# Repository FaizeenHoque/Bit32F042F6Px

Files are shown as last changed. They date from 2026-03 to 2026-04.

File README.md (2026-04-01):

# Bit32F042F6Px

Minimal STM32F042F6Px development board. USB-C, GPIO headers, onboard 3.3V regulation. No peripherals, no bloat.

Licensed under [CERN-OHL-S v2](LICENSE).

---

## Features

- STM32F042F6Px (32KB Flash, 6KB RAM, 48MHz)
- USB-C (USB 2.0 Full Speed via PA11/PA12)
- LP5912-3.3DRV LDO — 3.3V regulated output from 5V USB
- BOOT0 and RESET buttons
- SWD header (SWDIO, SWCLK, 3.3V, GND)
- GPIO headers — all available pins broken out
- Power indicator LED

---

## Bill of Materials

| Designator | Footprint | Qty | Value |
|---|---|:---:|---|
| BOOT1, RESET1 | SW_SPST_B3U-1000P | 2 | SW_Push |
| C1 | 0402 | 1 | 0.1µF |
| C2, C4, C5 | 0402 | 3 | 1µF |
| C3 | 0402 | 1 | 10µF |
| D1 | 0402 | 1 | LED |
| J1 | USB_C_Receptacle_GCT_USB4105-xx-A_16P_TopMnt_Horizontal | 1 | USB_C_Receptacle_USB2.0_16P |
| J2, J3 | PinHeader_1x09_P2.54mm_Vertical | 2 | Conn_01x09 |
| J4 | PinHeader_1x04_P2.54mm_Vertical | 1 | Conn_01x04 |
| R1, R2 | 0402 | 2 | 10kΩ |
| R3, R4 | 0402 | 2 | 5.1kΩ |
| R5 | 0402 | 1 | 1kΩ |
| U1 | TSSOP-20_4.4x6.5mm_P0.65mm | 1 | STM32F042F6Px |
| U2 | WSON-6-1EP_2x2mm_P0.65mm_EP1x1.6mm_ThermalVias | 1 | LP5912-3.3DRV |

---

## Pinout

| Header | Pins |
|---|---|
| J2 | +5V, +3V3 (x2), GND, GPIO\_6, GPIO\_7, GPIO\_8, GPIO\_9, GPIO\_10 |
| J3 | +5V, GND, GPIO\_0–GPIO\_5, GND |
| J4 | +3V3, SWDIO, SWCLK, GND |

---

## Schematic

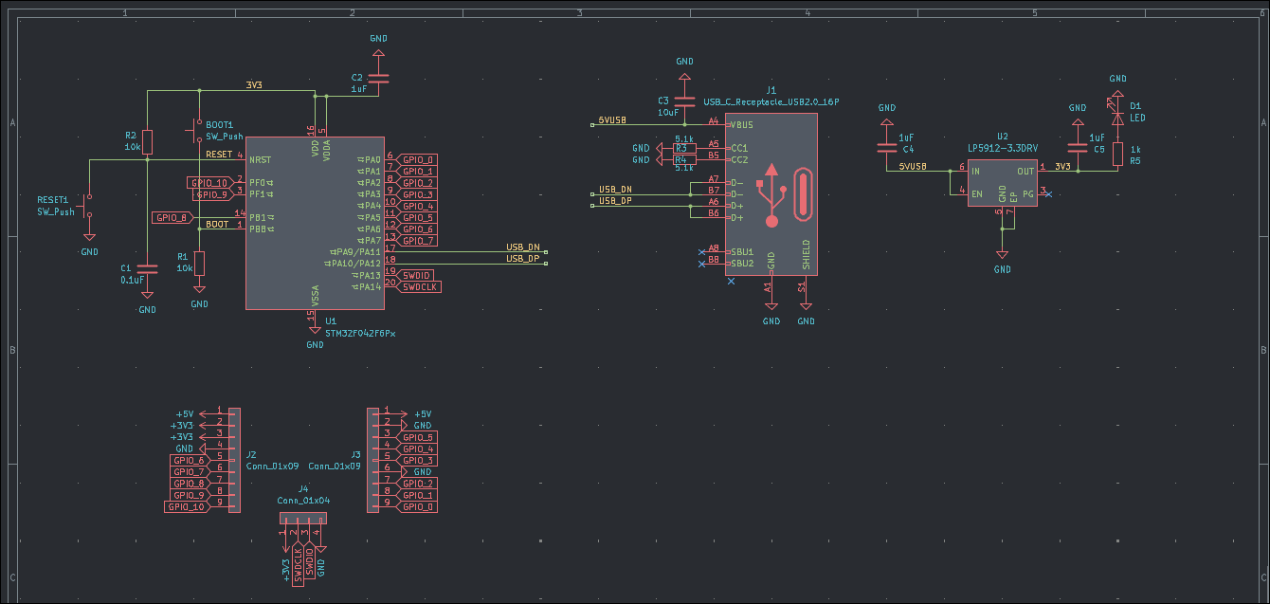
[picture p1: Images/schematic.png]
Schematic


---

## PCB Renders

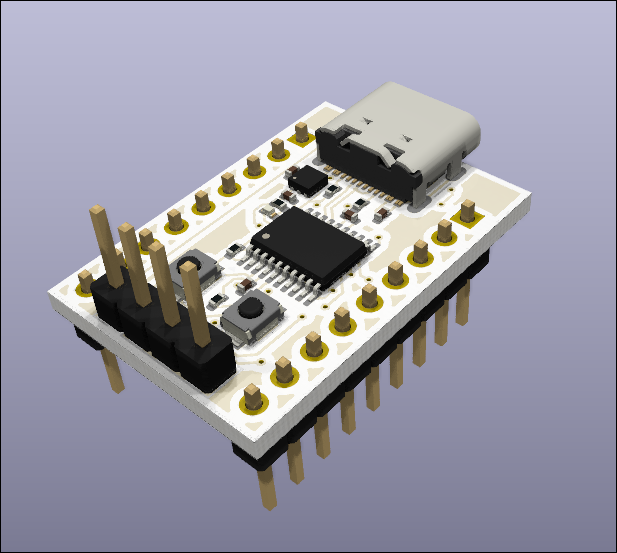
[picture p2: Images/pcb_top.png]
PCB Top

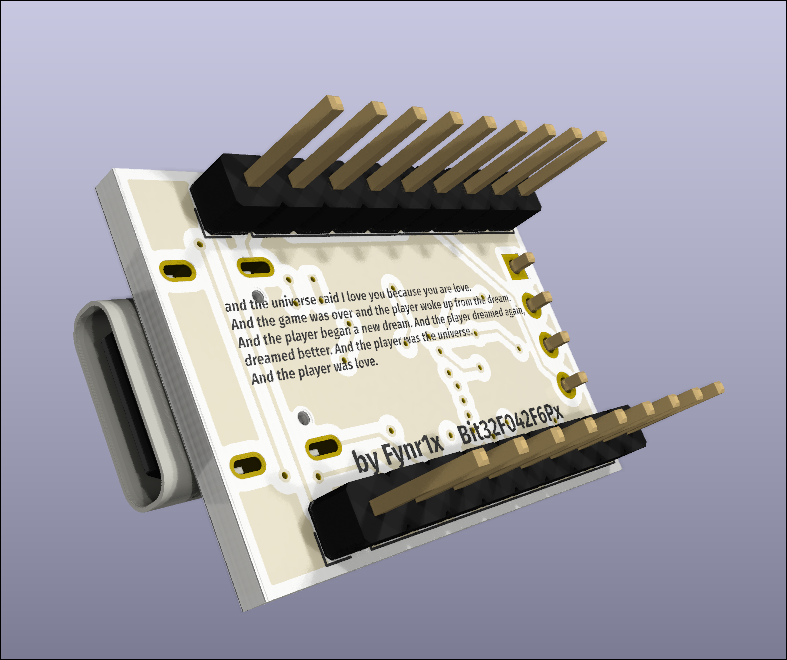
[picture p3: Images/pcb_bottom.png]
PCB Bottom


---

## BOM
> will be added later
---

## Programming
> will be added later
---

## Repository Structure

```
Bit32F042F6Px/
├── hardware/
│   ├── Bit32F042F6Px.kicad_sch
│   ├── Bit32F042F6Px.kicad_pcb
│   └── gerbers/
├── images/
│   ├── schematic.png
│   ├── pcb_top.png
│   ├── pcb_bottom.png
│   ├── render_top.png
│   └── render_bottom.png
├── LICENSE
└── README.md
```

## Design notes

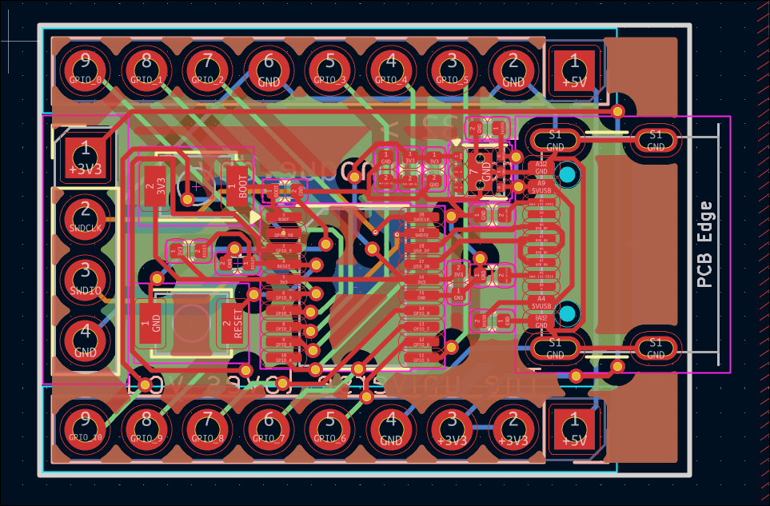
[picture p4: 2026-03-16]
Images/pcb.jpg

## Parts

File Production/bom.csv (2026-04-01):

Designator | Footprint | Quantity | Value
BOOT1, RESET1 | SW_SPST_B3U-1000P | 2 | SW_Push
C1 | 0402 | 1 | 0.1uF
C2, C4, C5 | 0402 | 3 | 1uF
C3 | 0402 | 1 | 10uF
D1 | 0402 | 1 | LED
J1 | USB_C_Receptacle_GCT_USB4105-xx-A_16P_TopMnt_Horizontal | 1 | USB_C_Receptacle_USB2.0_16P
J2, J3 | PinHeader_1x09_P2.54mm_Vertical | 2 | Conn_01x09
J4 | PinHeader_1x04_P2.54mm_Vertical | 1 | Conn_01x04
R1, R2 | 0402 | 2 | 10k
R3, R4 | 0402 | 2 | 5.1k
R5 | 0402 | 1 | 1k
U1 | TSSOP-20_4.4x6.5mm_P0.65mm | 1 | STM32F042F6Px
U2 | WSON-6-1EP_2x2mm_P0.65mm_EP1x1.6mm_ThermalVias | 1 | LP5912-3.3DRV

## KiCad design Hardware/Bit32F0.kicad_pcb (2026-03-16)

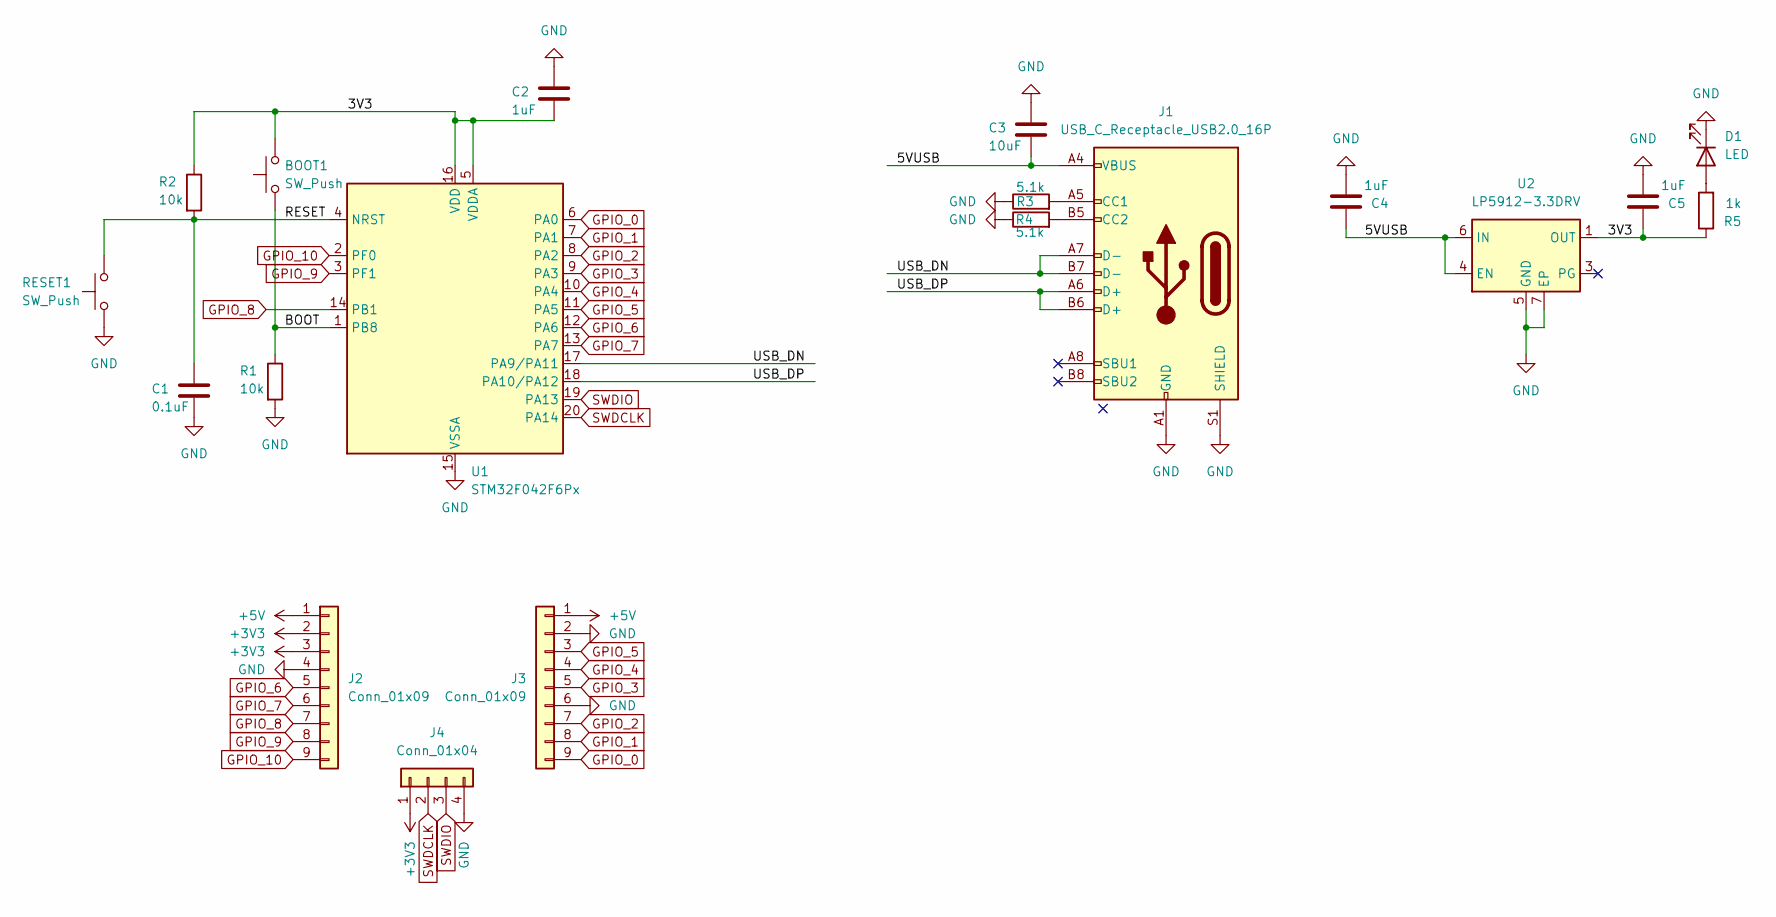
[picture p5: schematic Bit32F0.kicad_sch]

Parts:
BOOT1: SW_Push; SW_SPST_B3U-1000P
C1: 0.1uF; C_0402_1005Metric
C2, C4, C5: 1uF; C_0402_1005Metric
C3: 10uF; C_0402_1005Metric
D1: LED; LED_0402_1005Metric
J1: USB_C_Receptacle_USB2.0_16P; USB_C_Receptacle_GCT_USB4105-xx-A_16P_TopMnt_Horizontal
J2, J3: Conn_01x09; PinHeader_1x09_P2.54mm_Vertical
J4: Conn_01x04; PinHeader_1x04_P2.54mm_Vertical
R1, R2: 10k; R_0402_1005Metric
R3, R4: 5.1k; R_0402_1005Metric
R5: 1k; R_0402_1005Metric
RESET1: SW_Push; SW_SPST_B3U-1000P
U1: STM32F042F6Px; TSSOP-20_4.4x6.5mm_P0.65mm
U2: LP5912-3.3DRV; WSON-6-1EP_2x2mm_P0.65mm_EP1x1.6mm_ThermalVias

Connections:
+3V3: J2.2, J2.3, J4.1
+5V: J2.1, J3.1
/3V3: BOOT1.2, C2.2, C5.1, R2.1, R5.1, U1.5 (VDDA), U1.16 (VDD), U2.1 (OUT)
/5VUSB: C3.2, C4.1, J1.A4 (VBUS), J1.A9 (VBUS), J1.B4 (VBUS), J1.B9 (VBUS), U2.4 (EN), U2.6 (IN)
/BOOT: BOOT1.1, R1.1, U1.1 (PB8)
/RESET: C1.1, R2.2, RESET1.2, U1.4 (NRST)
/USB_DN: J1.A7 (D-), J1.B7 (D-), U1.17 (PA9/PA11)
/USB_DP: J1.A6 (D+), J1.B6 (D+), U1.18 (PA10/PA12)
GND: C1.2, C2.1, C3.1, C4.2, C5.2, D1.1 (K), J1.A1 (GND), J1.A12 (GND), J1.B1 (GND), J1.B12 (GND), J1.S1 (SHIELD), J2.4, J3.2, J3.6, J4.4, R1.2, R3.1, R4.1, RESET1.1, U1.15 (VSSA), U2.5 (GND), U2.7 (EP)
GPIO_0: J3.9, U1.6 (PA0)
GPIO_1: J3.8, U1.7 (PA1)
GPIO_2: J3.7, U1.8 (PA2)
GPIO_3: J3.5, U1.9 (PA3)
GPIO_4: J3.4, U1.10 (PA4)
GPIO_5: J3.3, U1.11 (PA5)
GPIO_6: J2.5, U1.12 (PA6)
GPIO_7: J2.6, U1.13 (PA7)
GPIO_8: J2.7, U1.14 (PB1)
GPIO_9: J2.8, U1.3 (PF1)
GPIO_10: J2.9, U1.2 (PF0)
unnamed: D1.2 (A), R5.2
unnamed: J1.A5 (CC1), R3.2
unnamed: J1.B5 (CC2), R4.2
SWDCLK: J4.2, U1.20 (PA14)
SWDIO: J4.3, U1.19 (PA13)

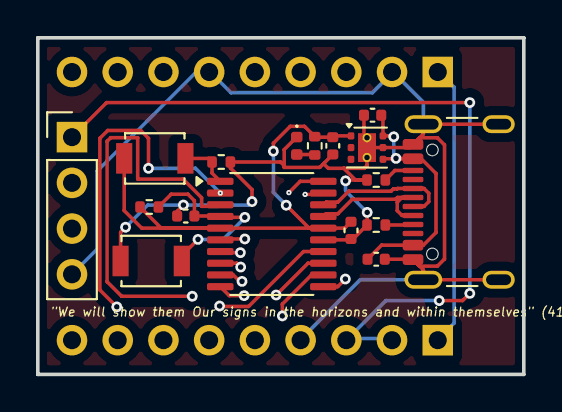
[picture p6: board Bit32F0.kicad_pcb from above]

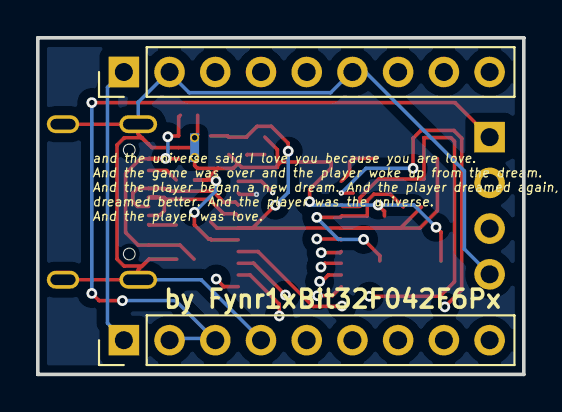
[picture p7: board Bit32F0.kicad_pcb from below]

Board: 4 copper layers, 27.0 x 18.7 mm, 19 parts (2 on the bottom side), 25 nets.

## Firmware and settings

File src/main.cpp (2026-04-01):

#include <Arduino.h>
#include <USBSerial.h>

#define LED_PIN PA5

void setup() {
    pinMode(LED_PIN, OUTPUT);
    USBSerial.begin(115200);
    delay(2000); // Give USB time to enumerate
    USBSerial.println("Bit32F042F6Px — board alive");
    USBSerial.println("Power rail: OK");
    USBSerial.println("GPIO: OK");
    USBSerial.println("USB CDC: OK (you're reading this)");
}

void loop() {
    digitalWrite(LED_PIN, HIGH);
    USBSerial.println("LED ON");
    delay(500);

    digitalWrite(LED_PIN, LOW);
    USBSerial.println("LED OFF");
    delay(500);
}

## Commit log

2026-03-16 Added Hardware files
    [Bit32F0.kicad_pcb, Bit32F0.kicad_sch, freerouting.dsn]
2026-03-16 Added pictures
    [Bit32F0.kicad_pcb, temp-freerouting.dsn]
2026-03-16 Update PCB section and remove render images
    Renamed section from 'Render' to 'PCB Renders' and removed render images.
2026-03-16 Add production files
    [bom.csv, designators.csv, positions.csv]
2026-04-01 Update BOM entries in bom.csv
    Removed BOM entries and added new entries with the same format.
    [bom.csv]
2026-04-01 Fix formatting issues in bom.csv
    [bom.csv]
2026-04-01 Add Bill of Materials to README
    Added a Bill of Materials section with component details.
2026-04-01 Add main Arduino sketch for LED control
    Initialize USB serial communication and control an LED.
